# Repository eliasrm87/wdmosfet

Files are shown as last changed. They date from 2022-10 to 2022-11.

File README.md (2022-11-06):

# WDSSR

WDSSR is a low side DC Mosfet based SSR board designed to drive resistive loads with and integrated watchdog able to detect some of the more common faults, report and protect it self from fire hazard.

## Watchdog capabilities

The integrated, fully analog, free of firmware, watchdog has the ability to detect:
 - Broken cable
 - Shorted switching Mosfet

For any of the cases described above, the board will “open” the series safety Mosfet and will trigger an alarm open collector signal for the control system to take further action, reducing the fire hazard resulting from an uncontrolled thermal runaway or defective wiring.

## Simplified principle of operation

 - The resistive load pulls the Drain to VCC
 - When Control is pulled up, the MOSFET “closes”, pulling its Drain close GND
 - Comparing voltages at Drain and Gate, a faulty MOSFET can be detected

| Gate | Drain | Result |
| ---- | ----- | --- |
| Low  | Low | Faulty - Source and drain  shorted |
| High | Low | Normal - ON |
| Low  | High  | Normal - OFF |
| High | High  | Faulty – Open or gate shorted to drain |

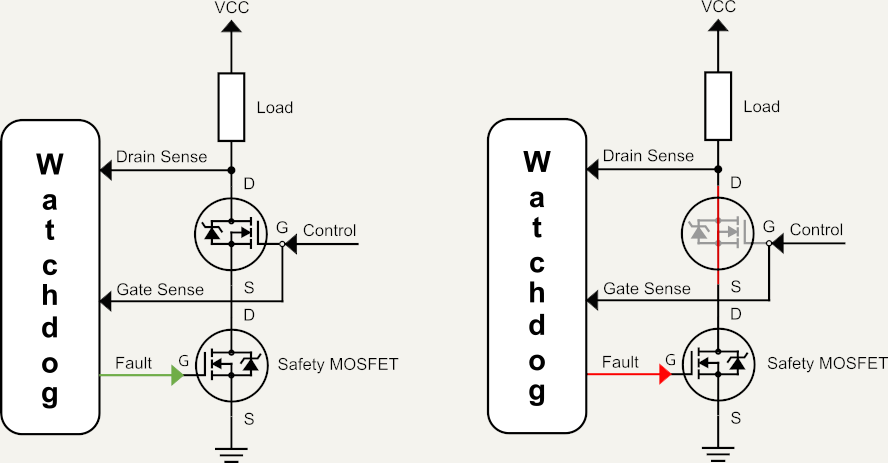
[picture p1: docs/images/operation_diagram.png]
Operation diagram


## Bill Of Material

You could consider using the included [Interactive Bill of Material](https://htmlpreview.github.io/?https://raw.githubusercontent.com/eliasrm87/wdssr/master/bom/WDSSR_ibom.html) for a better assembly experience.

|Qty|Reference(s) |Value |Part Number |LCSC Part # |
|---|---|---|---|---|
|1  |C1 |100n | |C14663 |
|1  |C2 |1u | |C15849 |
|1  |C3 |10n | |C14663 |
|1  |D1 |ABS6 | |C169532 |
|2  |D2, D4 |BAV70 | |C68978 |
|1  |D3 |LED_G | |C72043 |
|1  |D5 |LED_R | |C2286 |
|1  |D6 |D_Zener |MM3Z12VB |C891576 |
|1  |J1 |B2B-XH-A(LF)(SN)|B3B-XH-AM(LF)(SN) |C161870 |
|1  |J2 |1714968 |1714968 |C95692 |
|1  |J3 |Conn_01x02_Male | |C160332 |
|2  |Q1, Q2 |IRFR7440TRPBF |IRFR7440TRPBF |C97244 |
|2  |Q3, Q4 |BC846B,215 | |C87062 |
|2  |R1, R12 |2K | |C21190 |
|6  |R2, R5, R11, R14, R15, R16|10K | |C25804 |
|5  |R3, R7, R8, R9, R13 |100K | |C25803 |
|1  |R4 |1K | |C21190 |
|2  |R6, R17 |100 | |C22775 |
|1  |U1 |LM358DT | |C9418 |
|1  |U2 |TLP185 | |C7240 |

## Limitations

This design is not bullet proof and may fail to achieve it’s objective in certain cases:
 - The series safety Mosfet may overheat and fail exactly at the same time as the switching Mosfet
 - It is only tested and verified to work with resistive loads, like heaters. Uses of this design with inductive loads has not been yet tested and may need hardware modifications

### Front

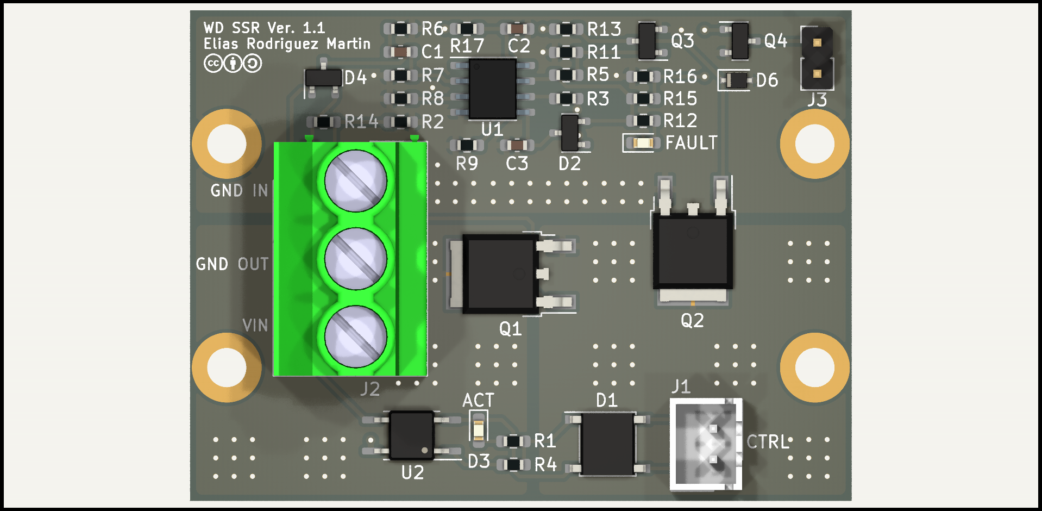
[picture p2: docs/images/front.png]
PCB front


### Back

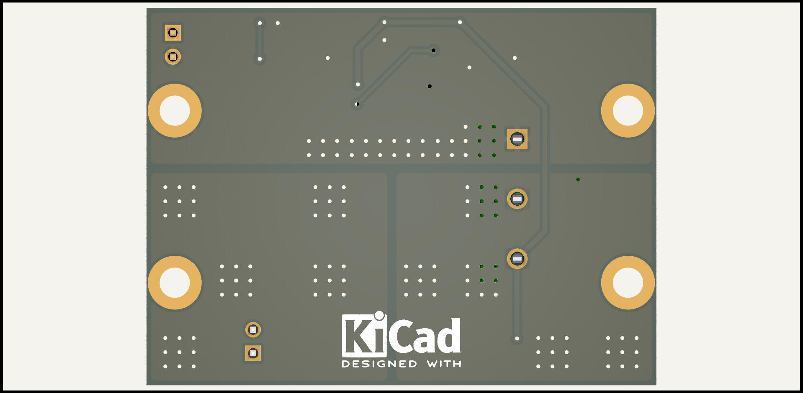
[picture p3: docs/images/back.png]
PCB back


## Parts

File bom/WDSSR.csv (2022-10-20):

Qty | Reference(s) | Value | Footprint | Datasheet | Part Number | LCSC Part #
1 | C1 | 100n | Capacitor_SMD:C_0603_1608Metric_Pad1.08x0.95mm_HandSolder | ~ |  | C14663
1 | C2 | 1u | Capacitor_SMD:C_0603_1608Metric_Pad1.08x0.95mm_HandSolder | ~ |  | C15849
1 | C3 | 10n | Capacitor_SMD:C_0603_1608Metric_Pad1.08x0.95mm_HandSolder | ~ |  | C14663
1 | D1 | ABS6 | Diode_SMD:Diode_Bridge_Diotec_ABS | https://diotec.com/tl_files/diotec/files/pdf/datasheets/abs2.pdf |  | C169532
2 | D2, D4 | BAV70 | Package_TO_SOT_SMD:SOT-23 | https://assets.nexperia.com/documents/data-sheet/BAV70_SER.pdf |  | C68978
1 | D3 | LED_G | LED_SMD:LED_0603_1608Metric_Pad1.05x0.95mm_HandSolder | ~ |  | C72043
1 | D5 | LED_R | LED_SMD:LED_0603_1608Metric_Pad1.05x0.95mm_HandSolder | ~ |  | C2286
1 | D6 | D_Zener | Diode_SMD:D_SOD-323F | ~ | MM3Z12VB | C891576
1 | J1 | B2B-XH-A(LF)(SN) | WDMosfet:LIB_B2B-XH-A(LF)(SN) | http://www.jst-mfg.com/product/pdf/eng/eXH.pdf | B3B-XH-AM(LF)(SN) | C161870
1 | J2 | 1714968 | WDMosfet:SHDR3W90P0X635_1X3_1905X1250X2150P | https://componentsearchengine.com/Datasheets/1/1714968.pdf | 1714968 | C95692
1 | J3 | Conn_01x02_Male | Connector_PinHeader_2.54mm:PinHeader_1x02_P2.54mm_Vertical | ~ |  | C160332
2 | Q1, Q2 | IRFR7440TRPBF | Package_TO_SOT_SMD:TO-252-2 | ~ | IRFR7440TRPBF | C97244
2 | Q3, Q4 | BC846B,215 | Package_TO_SOT_SMD:SOT-23 | https://assets.nexperia.com/documents/data-sheet/BC846_SER.pdf |  | C87062
2 | R1, R12 | 2K | Resistor_SMD:R_0603_1608Metric_Pad0.98x0.95mm_HandSolder | ~ |  | C21190
6 | R2, R5, R11, R14, R15, R16 | 10K | Resistor_SMD:R_0603_1608Metric_Pad0.98x0.95mm_HandSolder | ~ |  | C25804
5 | R3, R7, R8, R9, R13 | 100K | Resistor_SMD:R_0603_1608Metric_Pad0.98x0.95mm_HandSolder | ~ |  | C25803
1 | R4 | 1K | Resistor_SMD:R_0603_1608Metric_Pad0.98x0.95mm_HandSolder | ~ |  | C21190
2 | R6, R17 | 100 | Resistor_SMD:R_0603_1608Metric_Pad0.98x0.95mm_HandSolder | ~ |  | C22775
1 | U1 | LM358DT | Package_SO:SO-8_3.9x4.9mm_P1.27mm | http://www.ti.com/lit/ds/symlink/lm2904-n.pdf |  | C9418
1 | U2 | TLP185 | Package_SO:SOIC-4_4.55x3.7mm_P2.54mm | https://toshiba.semicon-storage.com/info/docget.jsp?did=11791&prodName=TLP185 |  | C7240

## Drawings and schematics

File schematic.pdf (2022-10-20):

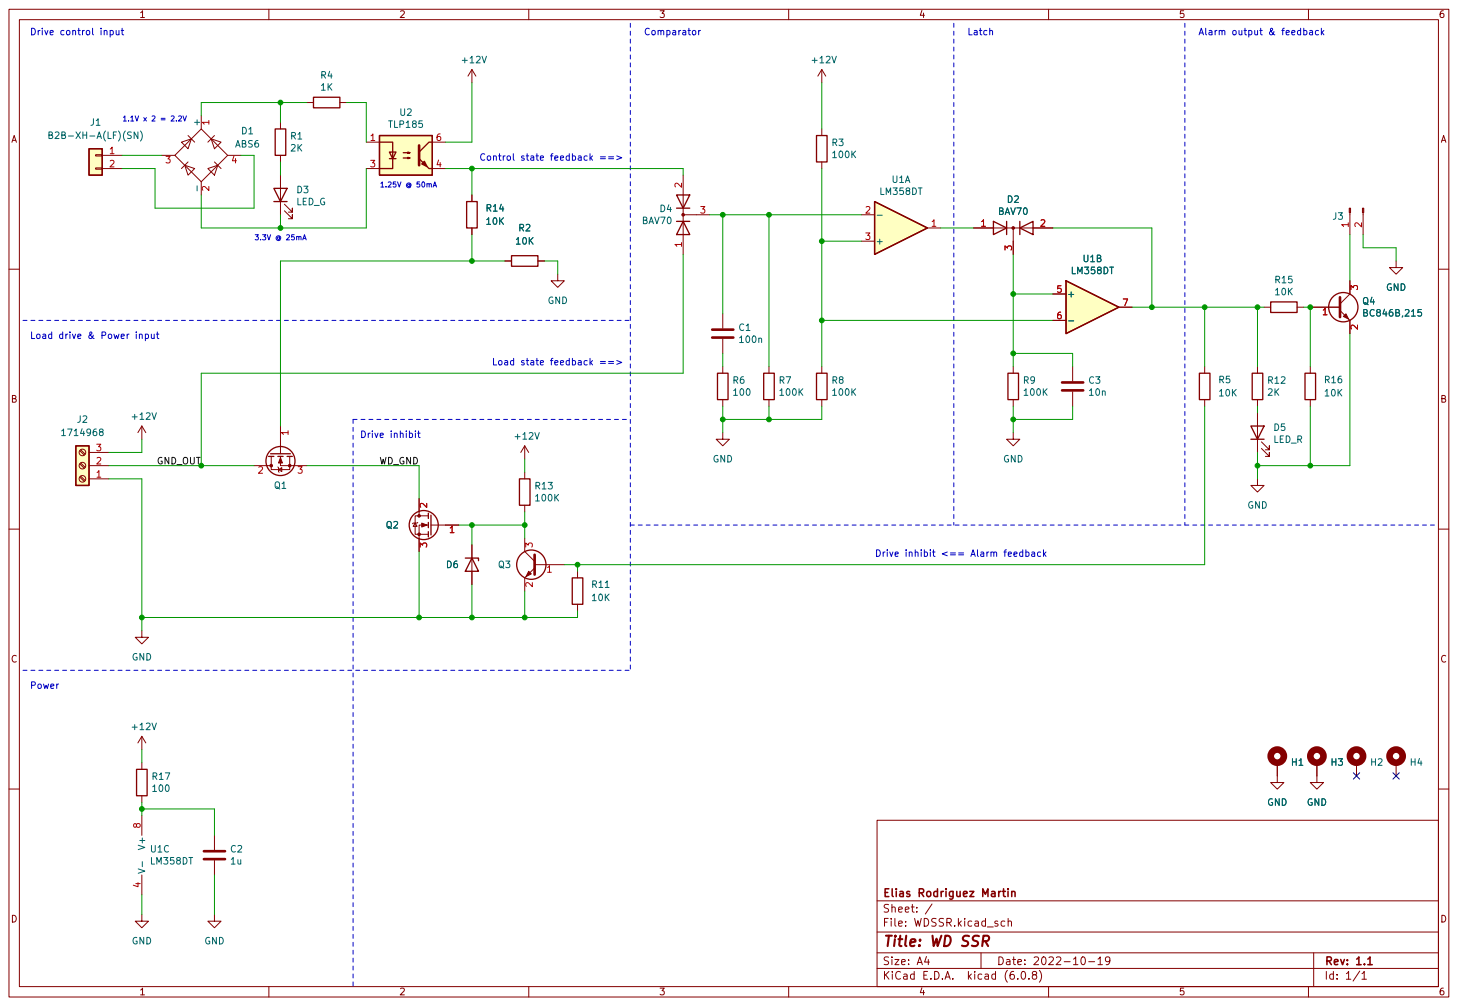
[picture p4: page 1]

File: WDSSR.kicad_sch Sheet: / Elias Rodriguez Martin

Id: 1/1 Title: WD SSR

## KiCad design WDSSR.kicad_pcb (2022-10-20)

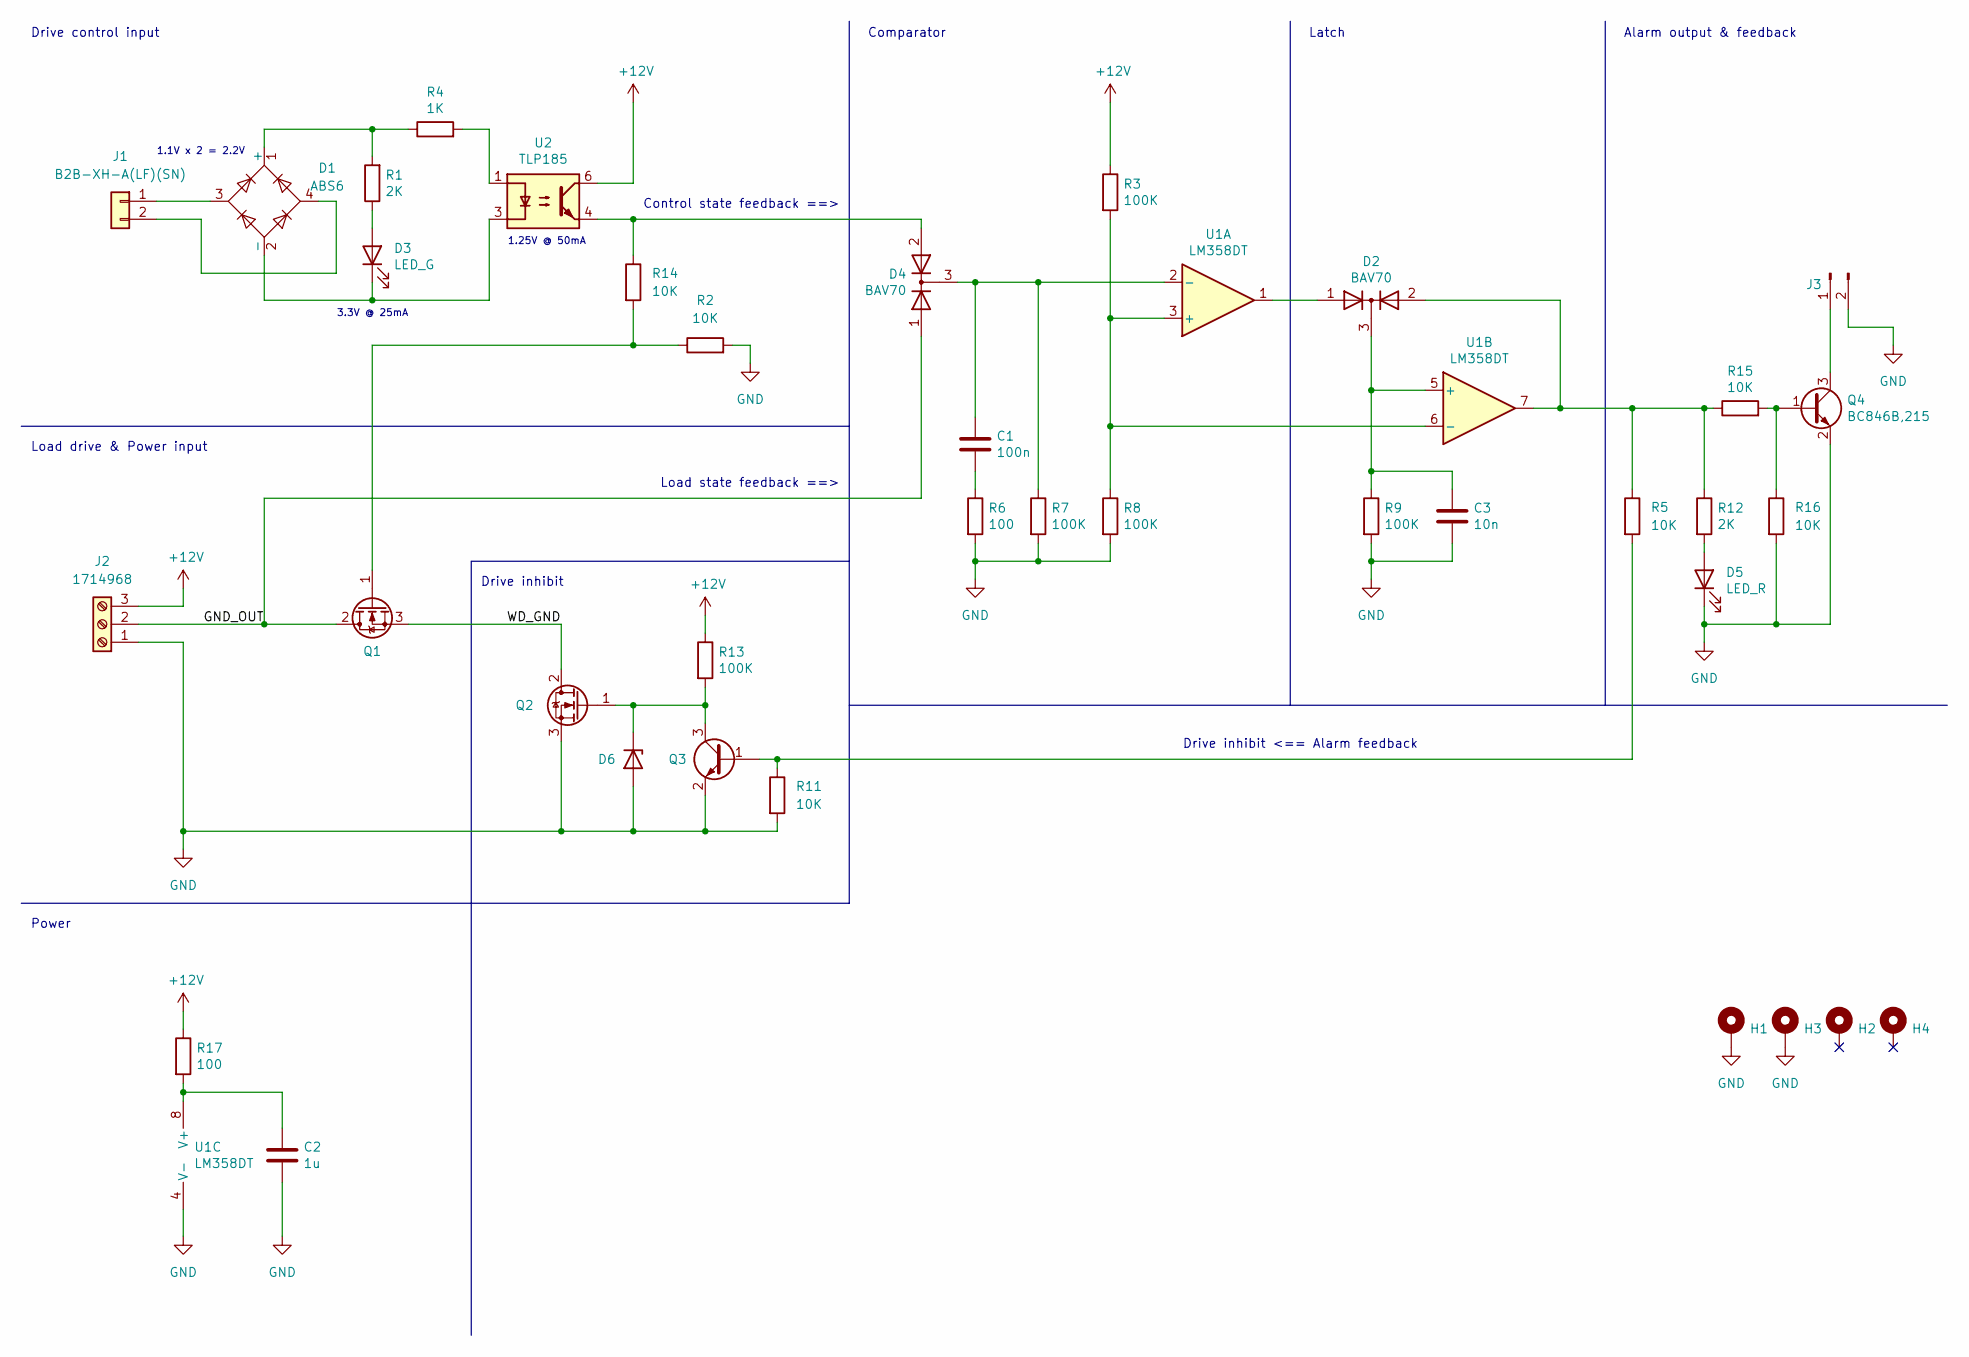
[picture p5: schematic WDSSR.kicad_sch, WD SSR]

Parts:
C1: 100n; C_0603_1608Metric_Pad1.08x0.95mm_HandSolder; Manufacturer_Part_Number CC0603KRX7R9BB104; LCSC Part # C14663
C2: 1u; C_0603_1608Metric_Pad1.08x0.95mm_HandSolder; Manufacturer_Part_Number CL10A105KB8NNNC; LCSC Part # C15849
C3: 10n; C_0603_1608Metric_Pad1.08x0.95mm_HandSolder; Manufacturer_Part_Number CC0603KRX7R9BB104; LCSC Part # C14663
D1: ABS6; Diode_Bridge_Diotec_ABS; Manufacturer_Part_Number ABS6-10; LCSC Part # C169532
D2, D4: BAV70; SOT-23; Manufacturer_Part_Number BAV70; LCSC Part # C68978
D3: LED_G; LED_0603_1608Metric_Pad1.05x0.95mm_HandSolder; Manufacturer_Part_Number 19-217/GHC-YR1S2/3T; LCSC Part # C72043
D5: LED_R; LED_0603_1608Metric_Pad1.05x0.95mm_HandSolder; Manufacturer_Part_Number KT-0603R; LCSC Part # C2286
D6: D_Zener; D_SOD-323F; Part Number MM3Z12VB; LCSC Part # C891576
H1, H2, H3, H4: MountingHole; MountingHole_3.2mm_M3_ISO7380_Pad; Manufacturer_Part_Number DNP
J1: B2B-XH-A(LF)(SN); LIB_B2B-XH-A(LF)(SN); Part Number B3B-XH-AM(LF)(SN); LCSC Part # C161870
J2: 1714968; SHDR3W90P0X635_1X3_1905X1250X2150P; Part Number 1714968; LCSC Part # C95692
J3: Conn_01x02_Male; PinHeader_1x02_P2.54mm_Vertical; Manufacturer_Part_Number RE-H022TD-1190(LF)(SN); LCSC Part # C160332
Q1, Q2: IRFR7440TRPBF; TO-252-2; Part Number IRFR7440TRPBF; LCSC Part # C97244
Q3, Q4: BC846B,215; SOT-23; Manufacturer_Part_Number BC846B,215; LCSC Part # C87062
R1, R12: 2K; R_0603_1608Metric_Pad0.98x0.95mm_HandSolder; Manufacturer_Part_Number 0603WAF2001T5E; LCSC Part # C21190
R2, R5, R11, R14, R15, R16: 10K; R_0603_1608Metric_Pad0.98x0.95mm_HandSolder; Manufacturer_Part_Number 0603WAF1002T5E; LCSC Part # C25804
R3, R7, R8, R9, R13: 100K; R_0603_1608Metric_Pad0.98x0.95mm_HandSolder; Manufacturer_Part_Number 0603WAF1003T5E; LCSC Part # C25803
R4: 1K; R_0603_1608Metric_Pad0.98x0.95mm_HandSolder; Manufacturer_Part_Number 0603WAF1001T5E; LCSC Part # C21190
R6, R17: 100; R_0603_1608Metric_Pad0.98x0.95mm_HandSolder; Manufacturer_Part_Number 0603WAF1000T5E; LCSC Part # C22775
U1: LM358DT; SO-8_3.9x4.9mm_P1.27mm; Manufacturer_Part_Number LM358DT; LCSC Part # C9418
U2: TLP185; SOIC-4_4.55x3.7mm_P2.54mm; Manufacturer_Part_Number TLP185(GB-TPL,SE(T; LCSC Part # C7240

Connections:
+12V: J2.3, R3.1, R13.1, R17.1, U2.6
/GND_OUT: D4.1 (A), J2.2, Q1.2 (D)
/WD_GND: Q1.3 (S), Q2.2 (D)
GND: C2.2, C3.2, D5.1 (K), D6.2 (A), H1.1, H3.1, J2.1, J3.2, Q2.3 (S), Q3.2 (E), Q4.2 (E), R2.2, R6.2, R7.2, R8.2, R9.2, R11.2, R16.2, U1.4 (V-)
unnamed: C1.1, D4.3 (K), R7.1, U1.2 (-)
unnamed: C1.2, R6.1
unnamed: C2.1, R17.2, U1.8 (V+)
unnamed: C3.1, D2.3 (K), R9.1, U1.5 (+)
unnamed: D1.1 (+), R1.2, R4.1
unnamed: D1.2 (-), D3.1 (K), U2.3
unnamed: D1.3, J1.1
unnamed: D1.4, J1.2
unnamed: D2.1 (A), U1.1
unnamed: D3.2 (A), R1.1
unnamed: D5.2 (A), R12.2
unnamed: J3.1, Q4.3 (C)
unnamed: D6.1 (K), Q2.1 (G), Q3.3 (C), R13.2
unnamed: Q4.1 (B), R15.2, R16.1
unnamed: R3.2, R8.1, U1.3 (+), U1.6 (-)
unnamed: R4.2, U2.1
unnamed: D2.2 (A), R5.1, R12.1, R15.1, U1.7
unnamed: Q3.1 (B), R5.2, R11.1
unnamed: D4.2 (A), R14.1, U2.4
unnamed: Q1.1 (G), R2.1, R14.2

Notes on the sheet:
Drive control input
Load state feedback ==>
Comparator
Control state feedback ==>
1.1V x 2 = 2.2V
Power
Alarm output & feedback
Drive inhibit
Drive inhibit <== Alarm feedback
1.25V @ 50mA
Load drive & Power input
Latch
3.3V @ 25mA

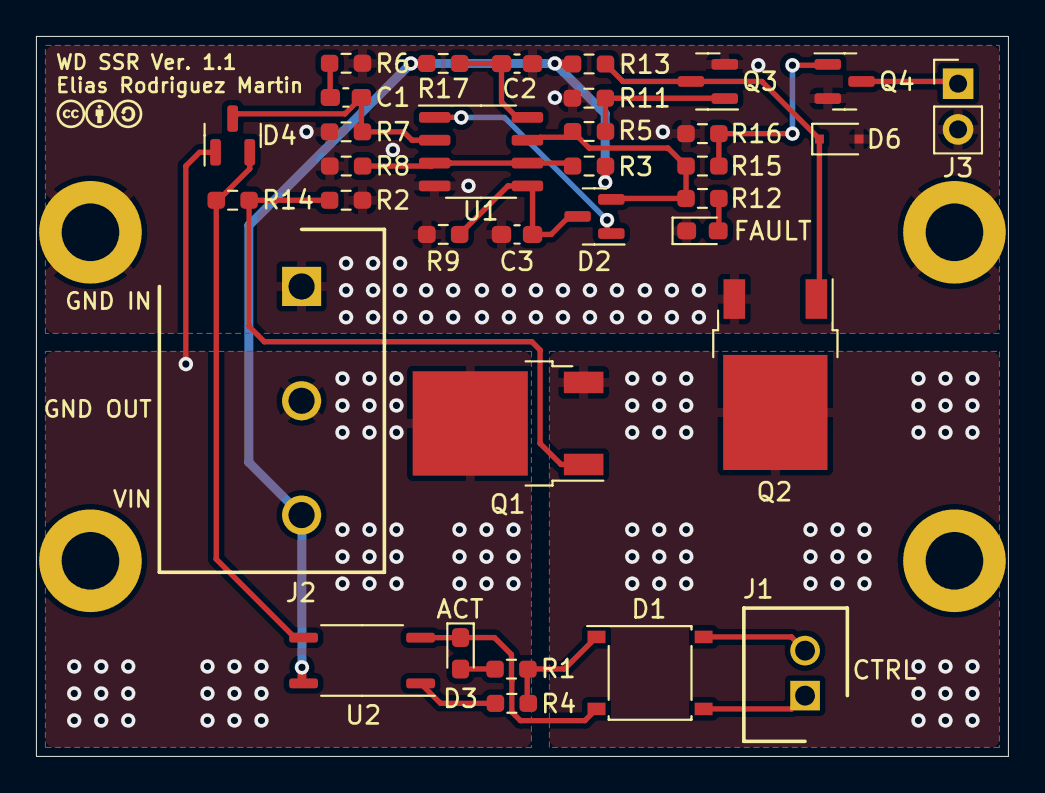
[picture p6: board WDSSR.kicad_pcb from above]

Board: 2 copper layers, 54.0 x 40.0 mm, 39 parts (0 on the bottom side), 24 nets.

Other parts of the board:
kibuzzard-6340B178: G***; kibuzzard-6340B178
